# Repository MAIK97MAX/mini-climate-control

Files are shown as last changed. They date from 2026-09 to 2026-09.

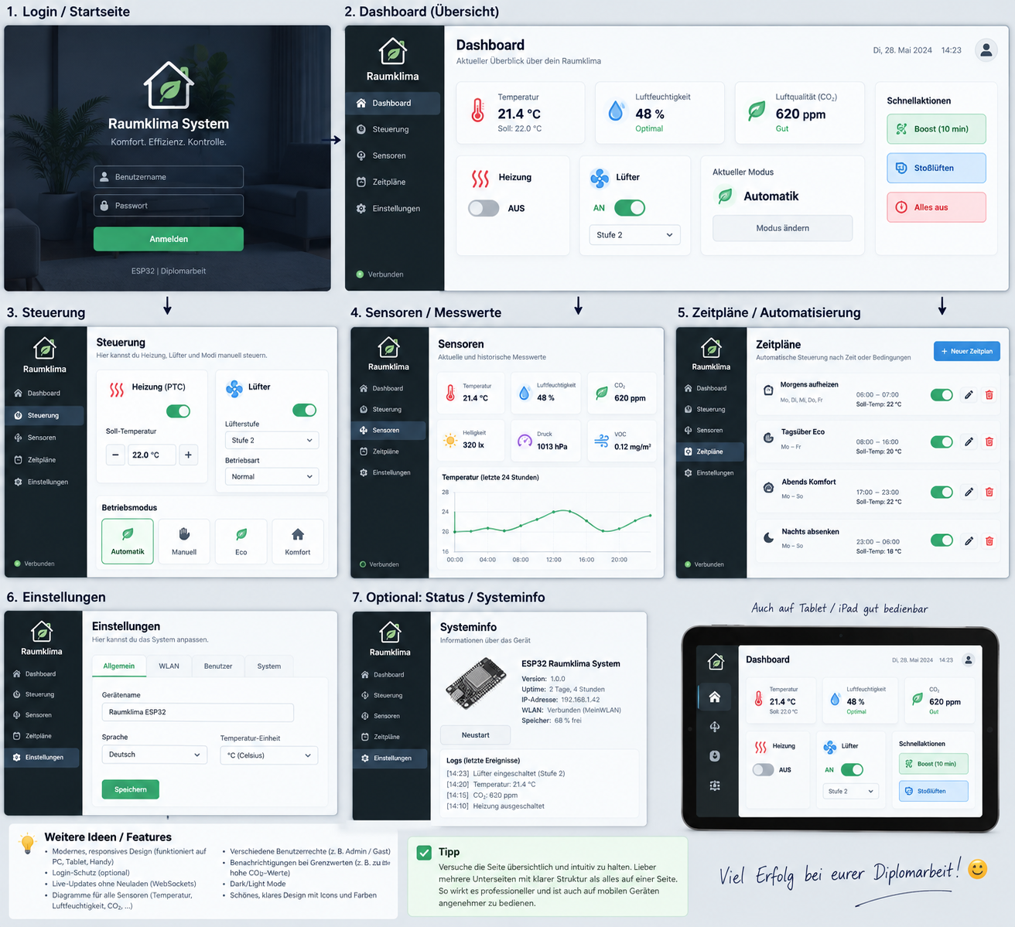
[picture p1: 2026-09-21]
software/inspiration/webdesign_inspiration.png

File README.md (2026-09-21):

# MDM Smart Home Solutions – Smart Climate Control

Embedded climate-control system developed as part of our HTL diploma project.

The system uses an ESP32-S3 as the central controller to monitor temperature sensors and control a thermoelectric heating/cooling unit and ventilation fans.

## Features

- ESP32-S3 central controller
- Thermoelectric heating and cooling
- PWM fan control
- Wireless temperature sensors
- Local OLED status display
- Wi-Fi web interface
- USB-C and 12 V power input
- Custom 4-layer PCB

## Repository

This repository contains the hardware design, firmware and related project files.

## Authors

Malik Jukic
David Sayfutdinov
Muhammet Karpuz

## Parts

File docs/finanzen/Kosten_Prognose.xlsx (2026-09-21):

 | Kostenprognose Diplomarbeit SCC-2109
Anzahl | Produkt | Kosten (vorraussichtlich) | Link
1x | Hauptplatine | ~15€ | n.V.
1x | Sensorplatinen | ~15€ | n.V.
1x | Modellraum | ~200-250€ | n.V.
1x | Thermoelektr. Heiz-/Kühlsystem | ~30€ | https://www.amazon.de/Thermoelektrischer-Halbleiterk%C3%BChlung-Thermoelektrisches-Entfeuchtungssystem-Praktikabilit%C3%A4t/dp/B08HZC5KZJ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
2x | 4-Pin Lüfter | ~30€ | https://www.amazon.de/GDSTIME-Hochdruck-K%C3%BChlventilator-Dual-Kugellager-L%C3%BCfter/dp/B08JPYKYTS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
1x | 12V-Netzteil | ~25€ | https://www.amazon.de/Jippofu-100V-240V-Bildschirm-Lautsprecher-Transformator/dp/B0FGV1ZBDT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
x | Bauteile (beide Platinen) | ~50-60€ | n.V.
 | ges: | ~365€-425€

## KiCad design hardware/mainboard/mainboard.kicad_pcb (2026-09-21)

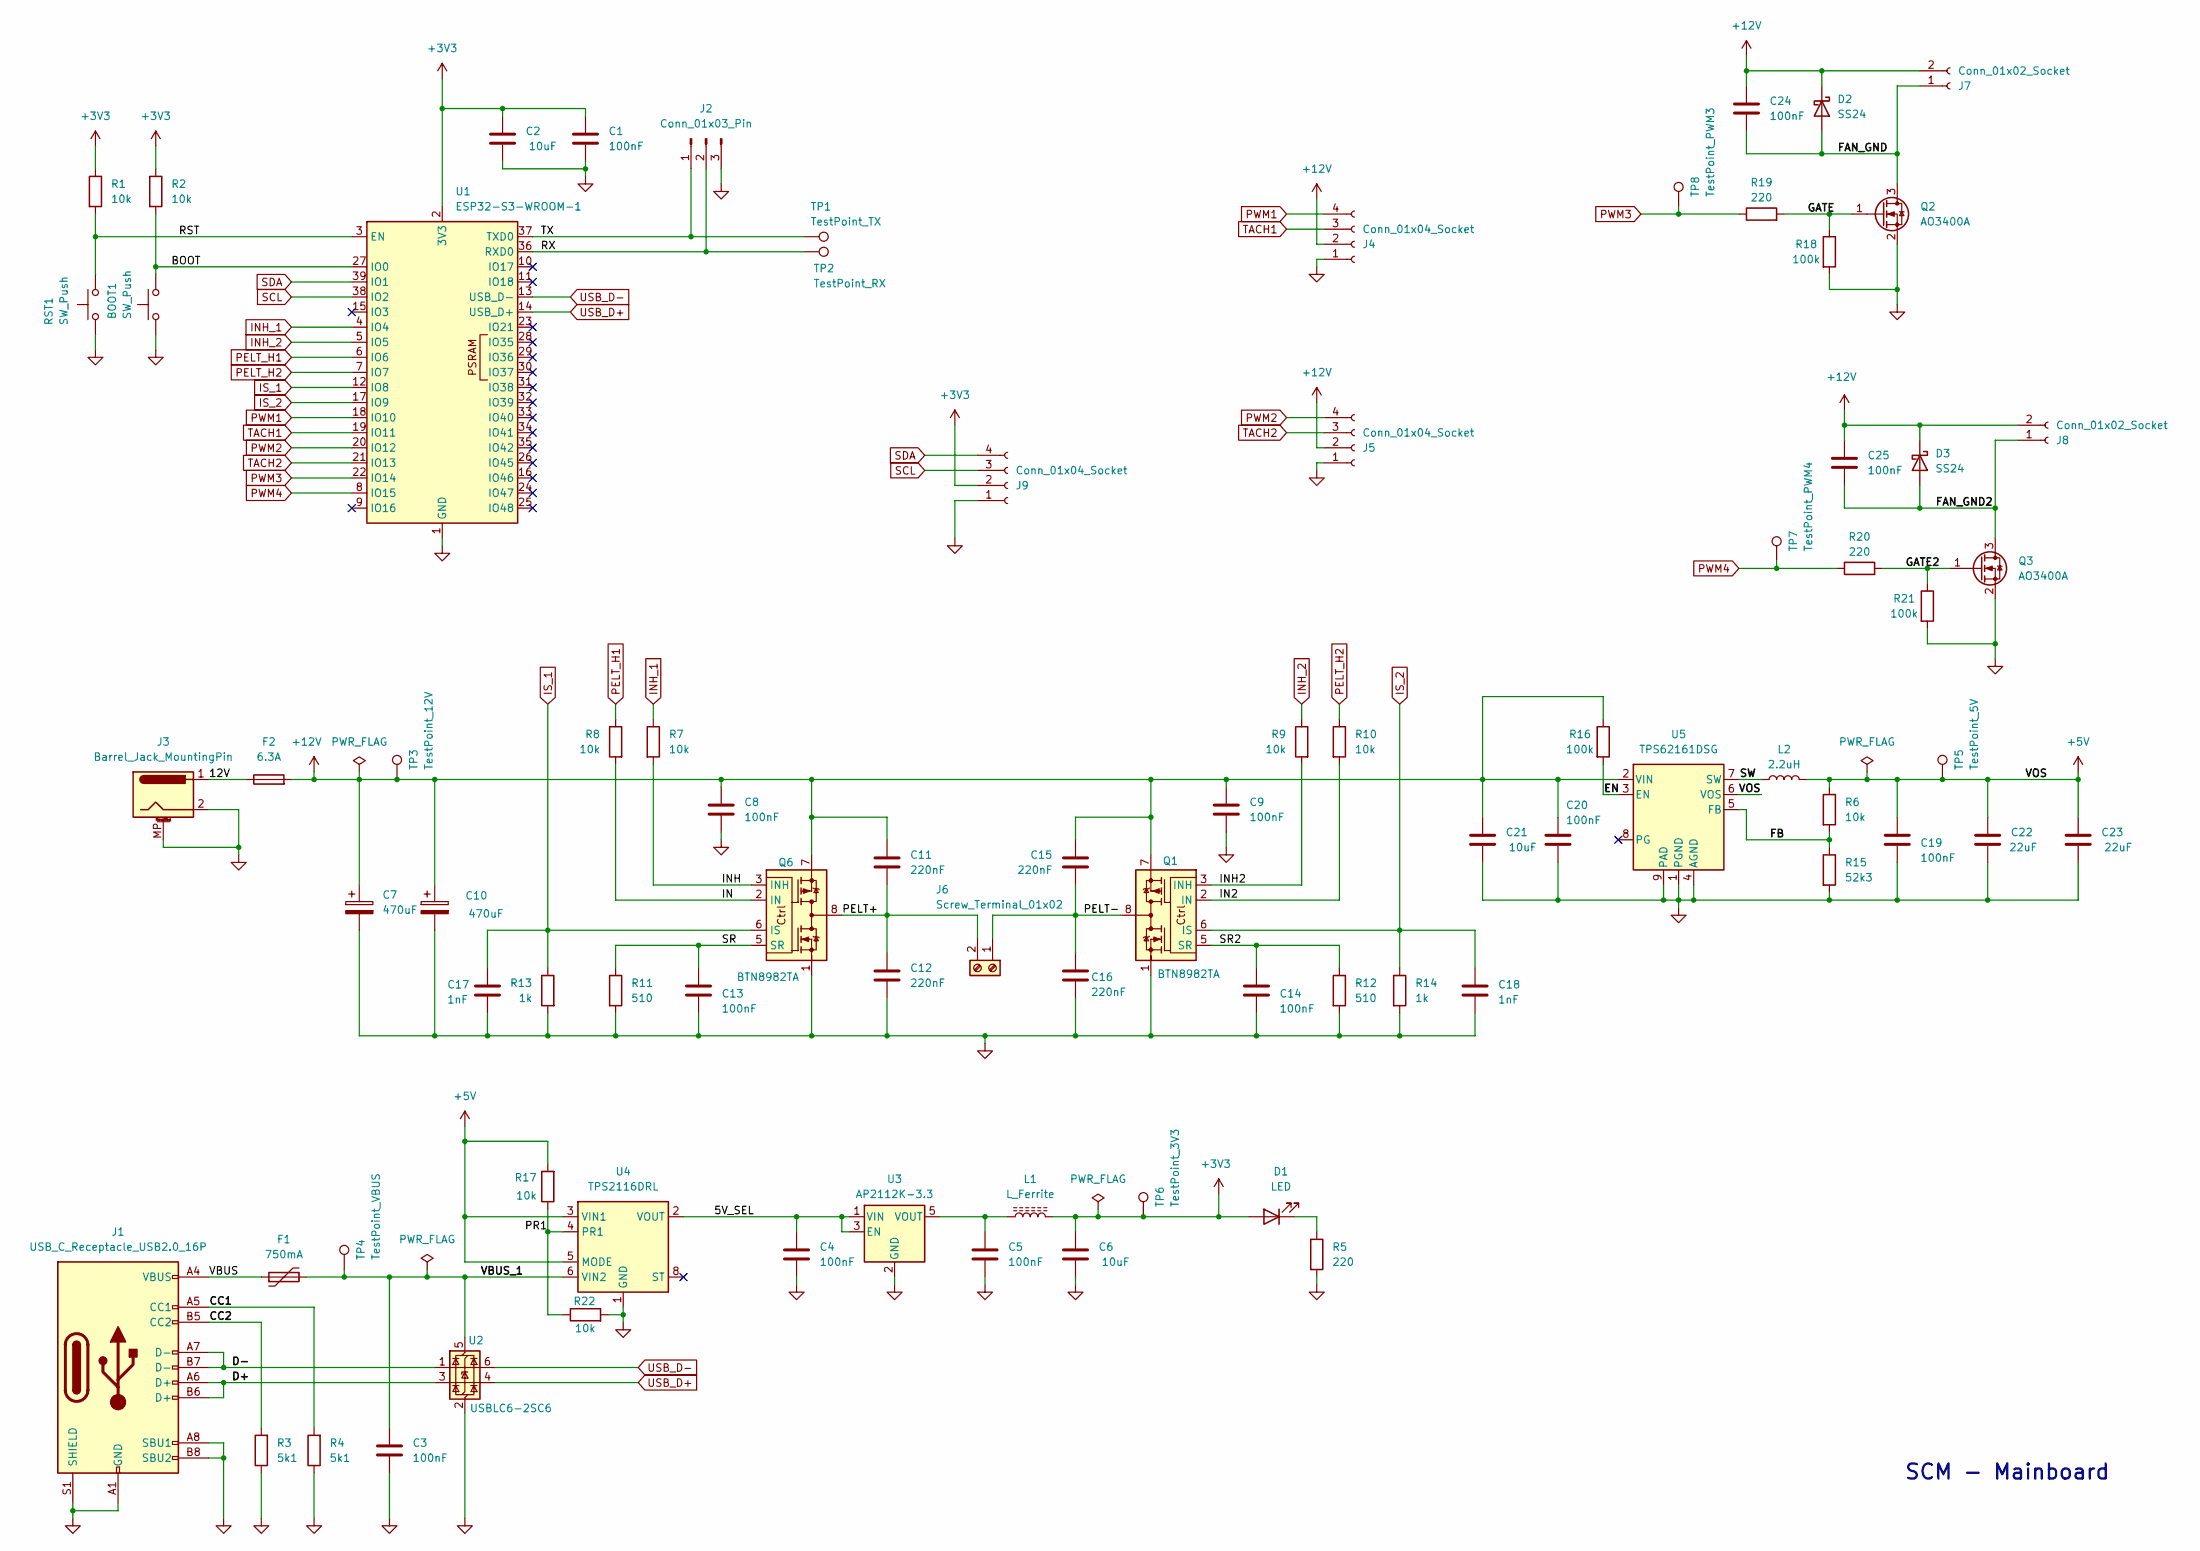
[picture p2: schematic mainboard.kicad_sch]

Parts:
BOOT1: SW_Push; SW_SPST_EVQP2_MiddlePushTravel_H2.5mm
C1, C3, C4, C5, C8, C9, C13, C14, C19, C20, C24, C25: 100nF; C_0603_1608Metric
C2, C6, C21: 10uF; C_0805_2012Metric
C7, C10: 470uF; CP_Radial_D10.0mm_P5.00mm
C11, C12, C15, C16: 220nF; C_0603_1608Metric
C17, C18: 1nF; C_0603_1608Metric
C22, C23: 22uF; C_0805_2012Metric
D1: LED; LED_0603_1608Metric
D2, D3: SS24; D_SMA
F1: 750mA; Fuse_1206_3216Metric
F2: 6.3A; Fuse_Littelfuse-NANO2-451_453
J1: USB_C_Receptacle_USB2.0_16P; USB_C_Receptacle_G-Switch_GT-USB-7010ASV
J2: Conn_01x03_Pin; PinHeader_1x03_P2.54mm_Vertical
J3: Barrel_Jack_MountingPin; BarrelJack_Horizontal
J4, J5: Conn_01x04_Socket; Molex_KK-254_AE-6410-04A_1x04_P2.54mm_Vertical
J6: Screw_Terminal_01x02; TerminalBlock_CUI_TB007-508-02_1x02_P5.08mm_Horizontal
J7, J8: Conn_01x02_Socket; JST_XH_S2B-XH-A-1_1x02_P2.50mm_Horizontal
J9: Conn_01x04_Socket; PinHeader_1x04_P2.54mm_Vertical
L1: L_Ferrite; L_0603_1608Metric
L2: 2.2uH; L_Coilcraft_LPS3010
Q1, Q6: BTN8982TA; TO-263-7_TabPin8
Q2, Q3: AO3400A; SOT-23
R1, R2, R6, R7, R8, R9, R10, R17, R22: 10k; R_0603_1608Metric
R3, R4: 5k1; R_0603_1608Metric
R5, R19, R20: 220; R_0603_1608Metric
R11, R12: 510; R_0603_1608Metric
R13, R14: 1k; R_0603_1608Metric
R15: 52k3; R_0603_1608Metric
R16, R18, R21: 100k; R_0603_1608Metric
RST1: SW_Push; SW_SPST_EVQP2_MiddlePushTravel_H2.5mm
TP1: TestPoint_TX; TestPoint_Pad_D1.0mm
TP2: TestPoint_RX; TestPoint_Pad_D1.0mm
TP3: TestPoint_12V; TestPoint_Pad_D1.0mm
TP4: TestPoint_VBUS; TestPoint_Pad_D1.0mm
TP5: TestPoint_5V; TestPoint_Pad_D1.0mm
TP6: TestPoint_3V3; TestPoint_Pad_D1.0mm
TP7: TestPoint_PWM4; TestPoint_Pad_D1.0mm
TP8: TestPoint_PWM3; TestPoint_Pad_D1.0mm
U1: ESP32-S3-WROOM-1
U2: USBLC6-2SC6; SOT-23-6
U3: AP2112K-3.3; SOT-23-5
U4: TPS2116DRL; SOT-583-8
U5: TPS62161DSG; WSON-8-1EP_2x2mm_P0.5mm_EP0.9x1.6mm_ThermalVias

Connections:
+3V3: C1.1, C2.1, C6.1, D1.2 (A), J9.2, L1.2, R1.1, R2.1, TP6.1, U1.2 (3V3)
+5V: C19.1, C22.1, C23.1, L2.2, R6.1, R17.2, TP5.1, U4.3 (VIN1), U4.5 (MODE), U5.6 (VOS)
+12V: C7.1, C8.1, C9.1, C10.1, C11.1, C15.1, C20.1, C21.1, C24.1, C25.1, D2.1 (K), D3.1 (K), F2.2, J4.2, J5.2, J7.2, J8.2, Q1.7, Q6.7, R16.1, TP3.1, U5.2 (VIN)
/5V_SEL: C4.1, U3.1 (VIN), U3.3 (EN), U4.2 (VOUT), U4.7 (VOUT)
/12V: F2.1, J3.1
/BOOT: BOOT1.2, R2.2, U1.27 (IO0)
/CC1: J1.A5 (CC1), R4.2
/CC2: J1.B5 (CC2), R3.2
/D+: J1.A6 (D+), J1.B6 (D+), U2.3 (I/O2)
/D-: J1.A7 (D-), J1.B7 (D-), U2.1 (I/O1)
/EN: R16.2, U5.3 (EN)
/FAN_GND: C24.2, D2.2 (A), J7.1, Q2.3 (D)
/FAN_GND2: C25.2, D3.2 (A), J8.1, Q3.3 (D)
/FB: R6.2, R15.1, U5.5 (FB)
/GATE: Q2.1 (G), R18.1, R19.2
/GATE2: Q3.1 (G), R20.2, R21.1
/IN: Q6.2 (IN), R8.2
/IN2: Q1.2 (IN), R10.2
/INH: Q6.3 (INH), R7.2
/INH2: Q1.3 (INH), R9.2
/PELT+: C11.2, C12.1, J6.2, Q6.4, Q6.8
/PELT-: C15.2, C16.1, J6.1, Q1.4, Q1.8
/PR1: R17.1, R22.1, U4.4 (PR1)
/RST: R1.2, RST1.2, U1.3 (EN)
/RX: J2.2, TP2.1, U1.36 (RXD0)
/SR: C13.1, Q6.5 (SR), R11.1
/SR2: C14.1, Q1.5 (SR), R12.1
/SW: L2.1, U5.7 (SW)
/TX: J2.1, TP1.1, U1.37 (TXD0)
/VBUS: F1.1, J1.A4 (VBUS), J1.A9 (VBUS), J1.B4 (VBUS), J1.B9 (VBUS)
/VBUS_1: C3.1, F1.2, TP4.1, U2.5 (VBUS), U4.6 (VIN2)
GND: BOOT1.1, C1.2, C2.2, C3.2, C4.2, C5.2, C6.2, C7.2, C8.2, C9.2, C10.2, C12.2, C13.2, C14.2, C16.2, C17.2, C18.2, C19.2, C20.2, C21.2, C22.2, C23.2, J1.A1 (GND), J1.A8 (SBU1), J1.A12 (GND), J1.B1 (GND), J1.B8 (SBU2), J1.B12 (GND), J1.S1 (SHIELD), J2.3, J3.2, J3.MP (MountPin), J4.1, J5.1, J9.1, Q1.1, Q2.2 (S), Q3.2 (S), Q6.1, R3.1, R4.1, R5.2, R11.2, R12.2, R13.2, R14.2, R15.2, R18.2, R21.2, R22.2, RST1.1, U1.1 (GND), U1.40 (GND), U1.41 (GND), U2.2 (GND), U3.2 (GND), U4.1 (GND), U5.1 (PGND), U5.4 (AGND), U5.9 (PAD); also elsewhere on the board
INH_1: R7.1, U1.4 (IO4)
INH_2: R9.1, U1.5 (IO5)
IS_1: C17.1, Q6.6 (IS), R13.1, U1.12 (IO8)
IS_2: C18.1, Q1.6 (IS), R14.1, U1.17 (IO9)
unnamed: D1.1 (K), R5.1
unnamed: C5.1, L1.1, U3.5 (VOUT)
PELT_H1: R8.1, U1.6 (IO6)
PELT_H2: R10.1, U1.7 (IO7)
PWM1: J4.4, U1.18 (IO10)
PWM2: J5.4, U1.20 (IO12)
PWM3: R19.1, TP8.1, U1.22 (IO14)
PWM4: R20.1, TP7.1, U1.8 (IO15)
SCL: J9.3, U1.38 (IO2)
SDA: J9.4, U1.39 (IO1)
TACH1: J4.3, U1.19 (IO11)
TACH2: J5.3, U1.21 (IO13)
USB_D+: U1.14 (USB_D+), U2.4 (I/O2)
USB_D-: U1.13 (USB_D-), U2.6 (I/O1)

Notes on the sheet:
SCM - Mainboard

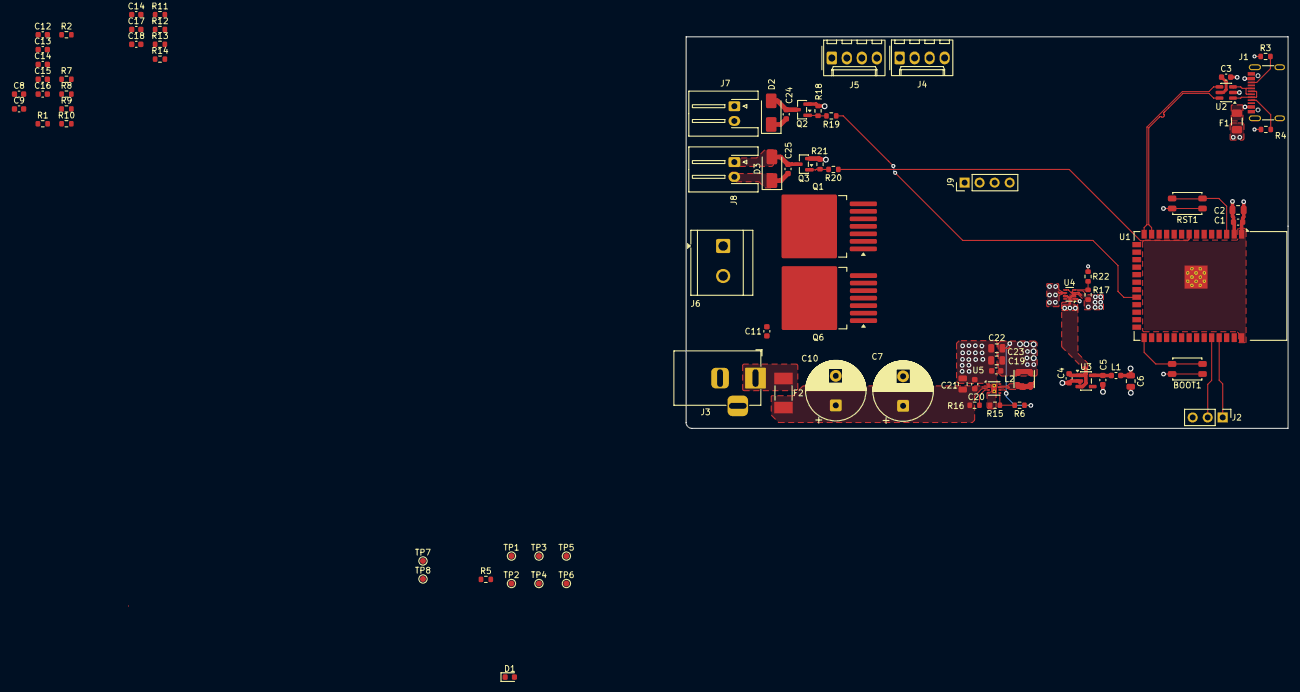
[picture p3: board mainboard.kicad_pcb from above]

Board: 4 copper layers, 101.8 x 66.2 mm, 83 parts (0 on the bottom side), 50 nets.

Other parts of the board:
C14#2: 4.7nF; C_0603_1608Metric

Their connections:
GND: C14#2.2; also elsewhere on the board

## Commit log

2026-07-28 added mainboard schematic and placed esp and usbc conn
    [mainboard.kicad_pcb, mainboard.kicad_sch]
2026-09-21 worked on loadswitch layout, linear regulator layout
    [mainboard.kicad_pcb, mainboard.kicad_sch]
2026-09-21 added docs folder, added Kosten_Prognose
    [Kosten_Prognose.xlsx]
2026-09-21 added Modellraum line to Kosten_Prognose
    [Kosten_Prognose.xlsx]
2026-09-21 added folder finanzen to docs
    [Kosten_Prognose.xlsx]
2026-09-21 finished Kosten_Prognose
    [Kosten_Prognose.xlsx]
2026-09-21 added folder hardware
    [mainboard.kicad_pcb, mainboard.kicad_sch]
2026-09-22 finished component placement
    [mainboard.kicad_pcb, mainboard.kicad_sch]
2026-09-24 finished h-bridge power routing
    [mainboard.kicad_pcb]
2026-09-28 signal routing for pwm fans and h-bridge
    [mainboard.kicad_pcb, mainboard.kicad_sch]
2026-10-05 revised routing and power stage routing
2026-10-14 routing reworks; adjusted display position, silkscreen adjustments
